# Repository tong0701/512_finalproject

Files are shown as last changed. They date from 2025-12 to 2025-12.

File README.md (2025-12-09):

# Bomb Master – 90s‑Style Handheld Reaction Game (ESP32‑C3 + CircuitPython)

## 1. Project Overview
Bomb Master is a 90s‑style handheld electronic reaction game. The OLED shows a command, you perform the matching physical action, the game checks timing/correctness, and you progress through 10 increasingly challenging levels.  
Hardware used: **ESP32‑C3 (Seeed XIAO), SSD1306 128×64 OLED, ADXL345 accelerometer, rotary encoder (with push button on D7 for game input), NeoPixel RGB LED, piezo buzzer, LiPo battery, independent hardware power switch.**

## 2. How to Play
### 2.1 Game Actions
- **LEFT** – rotate the encoder left  
- **RIGHT** – rotate the encoder right  
- **PRESS** – press the encoder/button (D7)  
- **SHAKE** – shake the device (detected by ADXL345)

### 2.2 Game Loop Structure
- Splash animation → "PRESS TO START"
- **Player name input** (3 characters, A-Z, using rotary encoder)
- Difficulty selection (Easy / Medium / Hard)
- Level start screen → press to ready → countdown (3,2,1,GO)
- Per‑move instruction (LEFT/RIGHT/PRESS; final move is SHAKE) with time limit and correctness check
- Level up after all moves; failure shows Game Over; after level 10 shows Win screen
- **High score board** (top 3 scores with player names) displayed after game ends

## 3. Difficulty Settings
- **Easy:** level time × 1.2  
- **Medium:** level time × 1.0  
- **Hard:** level time × 0.8  
SHAKE uses unified thresholds (magnitude > 13 or change > 3 or single change > 4, hold 1.5s); only time factor changes with difficulty.

## 4. Level Design (10 Levels)

| Level | Time Limit (base, s) | Moves | Notes |
|---|---|---|---|
| 1 | 25.0 | 3 | Last move = SHAKE |
| 2 | 22.0 | 4 | Last move = SHAKE |
| 3 | 19.0 | 5 | Last move = SHAKE |
| 4 | 17.0 | 6 | Last move = SHAKE |
| 5 | 14.0 | 7 | Last move = SHAKE |
| 6 | 12.0 | 8 | Last move = SHAKE |
| 7 | 10.0 | 9 | Last move = SHAKE |
| 8 | 8.5 | 10 | Last move = SHAKE |
| 9 | 7.0 | 11 | Last move = SHAKE |
| 10 | 6.0 | 12 | Last move = SHAKE |

Actual per‑difficulty time = base time × difficulty time factor above.

## 5. Hardware Components & Roles
- **ESP32‑C3 (XIAO):** runs CircuitPython game loop and state machine.  
- **SSD1306 OLED:** shows commands, timers, countdowns, and status.  
- **ADXL345 accelerometer:** detects SHAKE via magnitude/variation thresholds and hold time.  
- **Rotary encoder (CLK=D2, DT=D3, SW=D7):** primary input for LEFT/RIGHT rotations and PRESS action (D7 button for game input).  
- **NeoPixel (D0):** visual feedback (splash, success/fail, victory).  
- **Buzzer (D1, PWM):** audio cues for countdown, success, failure, splash.  
- **LiPo battery + independent hardware power switch:** portable power with physical on/off control (hardware switch, no GPIO, completely cuts battery connection).  

## 6. System & Circuit Diagrams
Documentation files are organized in the `Documentation/` folder:
- **Circuit diagrams** (`Documentation/circuit/`):
  - `circuit_diagrams.pdf` - Circuit schematic
  - `circuit_diagrams.kicad_sch` - KiCad source file
  - `circuit_diagrams.ps` - PostScript version
- **System diagrams** (`Documentation/system/`):
  - `systemdiagram.drawio.png` - System block diagram

## 7. Enclosure Design
- Handheld rectangular case; OLED window centered; encoder/button on front.  
- Cutouts for USB‑C and power switch; NeoPixel visible externally.  
- Internal battery compartment with access panel for service/debug.  
- 3D‑printed shell (e.g., PETG/PLA) for rigidity; non‑yellow filament per course constraint.

## 8. High Score System
- **Name Input**: Before difficulty selection, players enter a 3-character name (A-Z)
  - Use rotary encoder to select letters (rotate left/right)
  - Press button to confirm each character
  - After 3 characters are confirmed, press again to proceed
- **High Score Board**: Top 3 scores are saved to onboard memory (`highscores.txt`)
  - Scores are automatically sorted (highest first)
  - Displayed after game over or completion
  - Format: `1. ABC  1234`, `2. XYZ  1000`, `3. DEF  800`
  - New high scores trigger special animation
- **Persistent Storage**: High scores persist across power cycles (stored in microcontroller flash)

## 9. Running the Game
1. Flash **CircuitPython for ESP32‑C3** onto the XIAO.  
2. Copy required libs to `/lib/` on CIRCUITPY: `adafruit_ssd1306.mpy`, `adafruit_adxl34x.mpy`, `neopixel.mpy`, `adafruit_bus_device/` (and `adafruit_display_text/` if used).  
3. Copy `code.py` (from `src/` in this repo) to the root of CIRCUITPY as `code.py`.  
4. Eject and reset. Splash plays → enter name → choose difficulty → countdown → play.  

## 10. Repo Structure
```
bomb-master/
├── README.md                  # Project documentation
├── src/
│   └── code.py               # Main game code (CircuitPython)
├── docs/
│   └── CODE_STRUCTURE.md     # Code structure and flow guide
├── Documentation/
│   ├── circuit/              # Circuit diagrams
│   │   ├── circuit_diagrams.pdf
│   │   └── circuit_diagrams.kicad_sch
│   └── system/               # System diagrams
│       └── systemdiagram.drawio.png
└── lib/                       # Required CircuitPython libs (copy to device)
    ├── adafruit_ssd1306.mpy
    ├── adafruit_adxl34x.mpy
    ├── neopixel.mpy
    ├── adafruit_bus_device/
    └── adafruit_display_text/ (if used)
```

## 11. Future Improvements
- More move types or combo chains.  
- Richer 90s‑style sound/visual effects.  
- Dynamic difficulty scaling based on player performance.
- Additional statistics tracking (games played, average score, etc.).

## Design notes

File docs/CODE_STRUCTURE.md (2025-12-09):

# Bomb Master - Code Structure & Flow Guide

This document explains the complete code structure and execution flow of the Bomb Master game. Use this as a reference to understand how the game works and to prepare for questions.

---

## 📋 Table of Contents

1. [Overall Architecture](#overall-architecture)
2. [Hardware Setup](#hardware-setup)
3. [Core Components](#core-components)
4. [Game Flow](#game-flow)
5. [Key Functions Explained](#key-functions-explained)
6. [State Machine](#state-machine)
7. [Input Handling](#input-handling)
8. [Display & UI](#display--ui)
9. [Data Flow](#data-flow)

---

## 🏗️ Overall Architecture

The game follows a **single-file architecture** with clear sections:

```
code.py
├── Hardware Initialization (Lines 37-68)
├── Game Configuration (Lines 70-114)
├── Accelerometer Filter Class (Lines 116-187)
├── Encoder Class (Lines 189-252)
├── Helper Functions (Lines 261-323)
├── High Score Management (Lines 325-368)
├── Name Input (Lines 370-435)
├── High Score Board Display (Lines 437-465)
├── Difficulty Selection Menu (Lines 467-509)
├── UI Functions (Lines 511-706)
├── Animation Functions (Lines 642-798)
├── Game Logic Functions (Lines 800-999)
└── Main Game Loop (Lines 1001-1093)
```

**Design Pattern**: Event-driven with state machine (menu → game → results)

---

## 🔌 Hardware Setup

### Pin Mapping
- **OLED (I2C)**: SCL=D5, SDA=D4
- **Accelerometer (I2C)**: Shared bus with OLED
- **Rotary Encoder**: CLK=D2, DT=D3, SW=D7 (button)
- **NeoPixel**: D0
- **Buzzer (PWM)**: D1

### Hardware Initialization Order
1. Initialize I2C bus
2. Initialize OLED display
3. Initialize accelerometer (optional, with error handling)
4. Initialize NeoPixel (optional)
5. Initialize buzzer/PWM (optional)

**Note**: All hardware has try-except blocks to prevent crashes if hardware is missing.

---

## 🧩 Core Components

### 1. AccelerometerFilter Class
**Purpose**: Smooth accelerometer readings and auto-calibration

**How it works**:
- Uses 5-sample moving average filter
- Auto-calibrates on initialization (10 samples, calculates offset)
- Removes gravity offset (assumes Z-axis has ~9.8 m/s² gravity)
- Provides `get_magnitude()` for shake detection

**Key Methods**:
- `calibrate()`: Measures static position, calculates offset
- `read()`: Returns filtered (x, y, z) values
- `get_magnitude()`: Returns total acceleration magnitude

### 2. DebouncedEncoder Class
**Purpose**: Read rotary encoder input reliably

**How it works**:
- Detects CLK falling edge (simplified, fast response)
- Debounce time: 0.001s (very fast)
- Returns 'left' or 'right' direction
- `get_menu_navigation()`: Converts encoder direction to menu navigation (up/down)

**Key Methods**:
- `get_direction()`: Returns 'left' or 'right' or None
- `get_menu_navigation()`: Returns 'up' or 'down' or None
- `reset()`: Resets encoder state

### 3. Game Configuration
**Constants**:
- `TARGET_SCORE = 60`: Score needed to complete rotation actions
- `KNOB_MULTIPLIER = 30`: Points per encoder click
- `REACTION_TIME = 1.0`: Delay before showing new action

**DIFFICULTIES Dictionary**:
- `time_factor`: Multiplies level time (EASY: 1.2x, MEDIUM: 1.0x, HARD: 0.8x)
- `shake_threshold`: Unified magnitude threshold (13)
- `shake_change_threshold`: Accumulated change threshold (3)

**LEVELS List**:
- 10 levels, each with `time` and `moves`
- Time decreases, moves increase with level number

---

## 🎮 Game Flow

### Main Loop Structure

```
Power On
  ↓
Splash Animation (draw_upgraded_splash)
  ↓
"Press to Start" Screen (wait_for_press)
  ↓
Player Name Input (input_player_name)
  - 3 characters (A-Z)
  - Rotary encoder to select
  - Press to confirm each character
  ↓
Difficulty Selection Menu (show_difficulty_menu)
  ↓
┌─────────────────────────────────┐
│ Main Game Loop                  │
│                                 │
│  For each level (0-9):         │
│    ├─ Level Start Screen       │
│    ├─ Countdown (3-2-1-GO)     │
│    ├─ Run Level                │
│    │   ├─ For each move:       │
│    │   │   ├─ Choose action    │
│    │   │   ├─ Wait reaction    │
│    │   │   ├─ Action loop      │
│    │   │   └─ Check success    │
│    │   └─ Level complete       │
│    │                            │
│    ├─ Success?                  │
│    │   ├─ Yes → Next Level     │
│    │   └─ No → Game Over       │
│                                 │
│  All Levels Complete            │
│    └─ Win Screen                │
│                                 │
└─────────────────────────────────┘
  ↓
High Score Check
  - Check if score qualifies for top 3
  - If yes: Add to high score board with player name
  - Show "NEW HIGH SCORE!" animation (if qualified)
  ↓
High Score Board Display (show_high_score_board)
  - Show top 3 scores with player names
  - Press to continue
  ↓
Return to Splash (loop restarts)
```

### Detailed Level Execution Flow

```
run_level() is called
  ↓
Show "LEVEL X" screen → wait_for_press()
  ↓
run_countdown() → 3, 2, 1, GO!
  ↓
Initialize:
  - level_start_time = current time
  - score = 0
  - encoder.reset()
  ↓
┌──────────────────────────────────────┐
│ For each move in level:             │
│                                      │
│  1. Choose action:                  │
│     - Last move = SHAKE             │
│     - Others = random(LEFT/RIGHT/   │
│       PRESS)                         │
│                                      │
│  2. Reaction time delay (1.0s)      │
│     - Check if level time expired   │
│                                      │
│  3. Action execution loop:          │
│     ┌─────────────────────────────┐ │
│     │ while True:                 │ │
│     │   - Check level time        │ │
│     │   - Read encoder            │ │
│     │   - Read accelerometer      │ │
│     │   - Check button            │ │
│     │   - Update display          │ │
│     │   - Check action success    │ │
│     │   - Break if done/timeout   │ │
│     └─────────────────────────────┘ │
│                                      │
│  4. Success?                        │
│     - Yes: score += 10, continue    │
│     - No: return False, score       │
│                                      │
└──────────────────────────────────────┘
  ↓
All moves complete
  ↓
score += 50 (level bonus)
  ↓
draw_success_animation()
  ↓
Return True, score
```

---

## 🔑 Key Functions Explained

### Hardware Functions

#### `safe_show()`
**Purpose**: Safely update OLED display
- Wraps `display.show()` in try-except
- Prevents crashes from I2C errors

#### `tone(freq, duration)`
**Purpose**: Play buzzer sound
- Sets PWM frequency and duty cycle
- Plays for duration, then stops

### UI Functions

#### `draw_centered_text(text, y, color=1)`
**Purpose**: Draw text centered on screen
- Calculates x position: `(128 - text_width) // 2`
- Text width = `len(text) * 6` (6 pixels per char)

#### `draw_game_ui(target, progress_pct, level_time_pct, score, level)`
**Purpose**: Draw complete in-game UI
- Top: Level number (L1-L10) and Score
- Top progress bar: Level time remaining
- Center: Action instruction (LEFT/RIGHT/PRESS/SHAKE)
- Bottom progress bar: Action completion progress
- Updates every 0.05s (controlled in game loop)

#### `show_message_box(title, line1, line2, invert)`
**Purpose**: Display centered message with border
- Used for level start, game over, win screens

### Animation Functions

#### `draw_upgraded_splash()`
**Purpose**: Boot animation
- Phase 1: Bomb grows (8 frames)
- Phase 2: Explosion particles (15 frames)
- Phase 3: Title pops up (12 frames)
- Phase 4: Title flashes twice
- Only plays once per boot (`splash_played` flag)

#### `draw_success_animation()`
**Purpose**: Fireworks animation on level complete
- Creates 36 particles in circle
- Particles spread with gravity
- NeoPixel rainbow effect
- Plays for ~1.5 seconds total

#### `draw_fail_animation()`
**Purpose**: Flash animation on failure
- Inverts screen 5 times
- Red NeoPixel flash
- Descending buzzer tone

### Game Logic Functions

#### `input_player_name()`
**Purpose**: Input 3-character player name before difficulty selection
- Uses rotary encoder to select A-Z
- Press button to confirm each character
- Returns string of 3 characters
- Display shows current selection with cursor underline

#### `show_high_score_board()`
**Purpose**: Display top 3 high scores with player names
- Reads from `highscores.txt`
- Shows: `1. ABC  1234`, `2. XYZ  1000`, etc.
- Waits for button press to continue

#### `is_high_score(score)`
**Purpose**: Check if score qualifies for top 3
- Returns True if board has < 3 entries OR score > 3rd place score

#### `add_high_score(name, score)`
**Purpose**: Add new high score and maintain top 3
- Adds entry, sorts by score (descending), keeps only top 3
- Saves to `highscores.txt`
- Returns updated list

#### `show_difficulty_menu()`
**Purpose**: Difficulty selection screen
- Displays EASY, MEDIUM, HARD with cursor
- Uses encoder to navigate (up/down)
- Button press selects difficulty
- Returns selected difficulty string

#### `run_countdown()`
**Purpose**: 3-2-1-GO countdown
- Shows centered numbers
- Yellow NeoPixel, beep sound
- "GO!" with green NeoPixel, long beep

#### `run_level(level_idx, config, difficulty)`
**Purpose**: Execute a single level
- Parameters:
  - `level_idx`: Level number (0-9)
  - `config`: Level config dict (time, moves)
  - `difficulty`: Difficulty string
- Returns: `(success: bool, score: int)`

**Level Execution Details**:
1. Show level start screen → wait for press
2. Countdown
3. For each move:
   - Choose action (random or SHAKE for last)
   - Wait reaction time
   - Action loop:
     - Check level time limit
     - Detect input (encoder/button/shake)
     - Update progress bar
     - Check if action complete
   - If action failed → return False
4. All moves complete → return True with score

---

## 🎯 State Machine

The game uses an implicit state machine:

```
State: SPLASH
  - Play splash animation
  - Wait for button
  → Transition to MENU

State: MENU
  - Show difficulty selection
  - Navigate with encoder
  - Select with button
  → Transition to GAME

State: GAME
  - For each level:
    - Show level start → wait
    - Countdown
    - Execute moves
    - Check success/failure
  → Transition to RESULT (WIN/GAME_OVER)

State: RESULT
  - Show score/high score
  - Check for new high score
  - Wait for button
  → Transition to SPLASH (loop)
```

---

## 🎮 Input Handling

### Encoder Input (LEFT/RIGHT Actions)
**Detection**:
- `encoder.get_direction()` returns 'left' or 'right'
- Checked every loop iteration (0.01s delay)
- For LEFT action: accumulate score when direction == 'left'
- For RIGHT action: accumulate score when direction == 'right'
- Score increases by `KNOB_MULTIPLIER` (30) per click
- When `accumulated_score >= TARGET_SCORE` (60), action complete

### Button Input (PRESS Action)
**Detection**:
- `button.value == False` means pressed (pull-up resistor)
- Checked every loop iteration
- When PRESS action active and button pressed → action complete

### Accelerometer Input (SHAKE Action)
**Detection** (Multi-threshold approach):
1. **Magnitude trigger**: `current_magnitude > 13`
2. **Change trigger**: `accumulated_change > 3` (within 0.2s window)
3. **Big change trigger**: `magnitude_change > 4` (single large change)

**Hold mechanism**:
- Once triggered, must hold for `shake_hold_duration` (1.5s)
- Progress bar shows hold progress
- If trigger conditions met, action completes after hold time

### Menu Navigation
**Detection**:
- `encoder.get_menu_navigation()` converts encoder direction to menu direction
- Right rotation = Down (next option)
- Left rotation = Up (previous option)
- Menu polls at high frequency (0.001s delay) for responsiveness

---

## 📺 Display & UI

### Screen Layout (128x64 pixels)

**In-Game UI** (`draw_game_ui`):
```
┌────────────────────────────────────┐
│ L1              S:100              │  ← Top bar (Level & Score)
│ ━━━━━━━━━━━━━━━━━━━━━━━━━━━━━━━━━ │  ← Level time progress bar
│                                    │
│           CUT BLUE                 │  ← Action theme
│           << LEFT                  │  ← Action instruction
│                                    │
│                                    │
│        ━━━━━━━━━━━━━━━━━━         │  ← Action progress bar
└────────────────────────────────────┘
```

**Menu UI** (`show_difficulty_menu`):
```
┌────────────────────────────────────┐
│                                    │
│           > EASY                   │  ← y=8
│             MEDIUM                 │  ← y=21
│             HARD                   │  ← y=34
│                                    │
│         Rotate/Press               │  ← y=48
└────────────────────────────────────┘
```

**Message Box** (`show_message_box`):
```
┌────────────────────────────────────┐
│ ╔═══════════════════════════════╗ │
│ ║          TITLE                ║ │  ← Title (y=15)
│ ║                               ║ │
│ ║          Line 1               ║ │  ← Line 1 (y=30)
│ ║          Line 2               ║ │  ← Line 2 (y=42)
│ ╚═══════════════════════════════╝ │
└────────────────────────────────────┘
```

### Display Update Strategy
- **Game UI**: Updated every 0.05s (20 FPS) in game loop
- **Menu**: Updated every loop iteration (high frequency)
- **Animations**: Frame-based (0.04-0.05s per frame)

---

## 📊 Data Flow

### Score Flow
```
Each successful action: +10 points
Level complete bonus: +50 points
Total score = sum of all level scores
```

### High Score Flow
```
Game ends
  ↓
Check: is_high_score(total_score)?
  - Compares with 3rd place or checks if board has < 3 entries
  ↓
Yes → Add player_name and score to high score board
      → Sort and keep top 3
      → Save to highscores.txt (format: "NAME,SCORE")
      → Show "NEW HIGH SCORE!" animation
  ↓
Show high score board (top 3 with names)
  ↓
Press to continue
```

### Name Input Flow
```
After splash screen
  ↓
Display "ENTER NAME"
  ↓
For each of 3 characters:
  - Rotate encoder: Select A-Z
  - Press: Confirm character → Move to next
  ↓
After 3rd character confirmed:
  - Press again → Proceed to difficulty selection
```

### Time Management
```
Level start:
  level_start_time = current_time
  level_time_limit = base_time * difficulty_factor

Each loop:
  elapsed = current_time - level_start_time
  level_time_pct = elapsed / level_time_limit
  
  if elapsed >= level_time_limit:
    → Game Over
```

### Action Progress Tracking

**Rotation Actions (LEFT/RIGHT)**:
```
accumulated_score = 0
Each encoder click in correct direction:
  accumulated_score += KNOB_MULTIPLIER (30)
  
progress_pct = accumulated_score / TARGET_SCORE (60)
  
When progress_pct >= 1.0:
  → Action complete
```

**SHAKE Action**:
```
shake_triggered = False
shake_trigger_time = 0

When shake detected:
  shake_triggered = True
  shake_trigger_time = current_time

progress_pct = (current_time - shake_trigger_time) / 1.5

When progress_pct >= 1.0:
  → Action complete
```

---

## 🔄 Common Patterns

### Error Handling Pattern
```python
try:
    # Hardware operation
    display.show()
except:
    pass  # Fail silently, prevent crash
```

### Hardware Check Pattern
```python
if pixels:
    try:
        pixels.fill((255, 0, 0))
    except:
        pass
```

### Non-blocking Loop Pattern
```python
while True:
    # Do work
    # Check conditions
    time.sleep(0.01)  # Prevent freeze
```

### Progress Bar Drawing Pattern
```python
# Draw border
display.rect(x, y, width, height, 1)

# Calculate fill
fill_w = int(progress_pct * (width - 2))
fill_w = min(max(fill_w, 0), width - 2)  # Clamp

# Draw fill
if fill_w > 0:
    display.fill_rect(x + 1, y + 1, fill_w, height - 2, 1)
```

---

## 📝 Key Constants Reference

| Constant | Value | Purpose |
|---|---|---|
| `TARGET_SCORE` | 60 | Score needed to complete rotation actions |
| `KNOB_MULTIPLIER` | 30 | Points per encoder click |
| `REACTION_TIME` | 1.0s | Delay before showing new action |
| `shake_hold_duration` | 1.5s | Time to hold shake action |
| `debounce_time` | 0.001s | Encoder debounce time |
| `display_update_interval` | 0.05s | UI update frequency |

---

## 🎓 Understanding the Code for Questions

### How to explain the game flow:
1. **Start**: Splash animation → difficulty selection → game begins
2. **Level structure**: 10 levels, increasing difficulty
3. **Move execution**: Random actions (LEFT/RIGHT/PRESS), last is always SHAKE
4. **Scoring**: +10 per move, +50 per level
5. **Time management**: Each level has time limit, difficulty affects time
6. **End conditions**: Time runs out → Game Over, all levels complete → Win

### How to explain input detection:
1. **Encoder**: Detects CLK falling edge, checks DT pin for direction
2. **Button**: Pull-up resistor, False = pressed
3. **Shake**: Multi-threshold (magnitude + change + big change), must hold 1.5s

### How to explain filtering:
1. **Accelerometer**: 5-sample moving average, auto-calibrates on boot
2. **Encoder**: Debounce (0.001s) to prevent noise

### How to explain difficulty:
- Only affects **time factor** (EASY: 1.2x, MEDIUM: 1.0x, HARD: 0.8x)
- Shake thresholds are **unified** across all difficulties
- More time = easier to complete moves

---

## 🚀 Quick Reference for Common Questions

**Q: How does the encoder work?**
- A: Detects CLK falling edge, checks DT pin state to determine direction. Uses debouncing (0.001s) for reliability.

**Q: How is shake detected?**
- A: Three triggers: total magnitude > 13, accumulated change > 3, or single change > 4. Must hold for 1.5 seconds after trigger.

**Q: How does scoring work?**
- A: +10 points per successful action, +50 bonus per completed level. Top 3 high scores saved with player names to `highscores.txt`.

**Q: What happens when time runs out?**
- A: Game immediately ends, shows Game Over screen, checks for high score.

**Q: How are actions chosen?**
- A: Random selection from LEFT/RIGHT/PRESS for first N-1 moves. Last move is always SHAKE.

**Q: How does difficulty affect gameplay?**
- A: Only affects time limit (multiplier: 1.2x/1.0x/0.8x). All other mechanics stay the same.

**Q: How does the high score board work?**
- A: Before difficulty selection, players enter 3-character name (A-Z) using encoder. Top 3 scores are saved with names to onboard memory. High score board displays after game ends.

---

**End of Guide**

Use this document to understand the code structure and prepare for technical questions about the game implementation.

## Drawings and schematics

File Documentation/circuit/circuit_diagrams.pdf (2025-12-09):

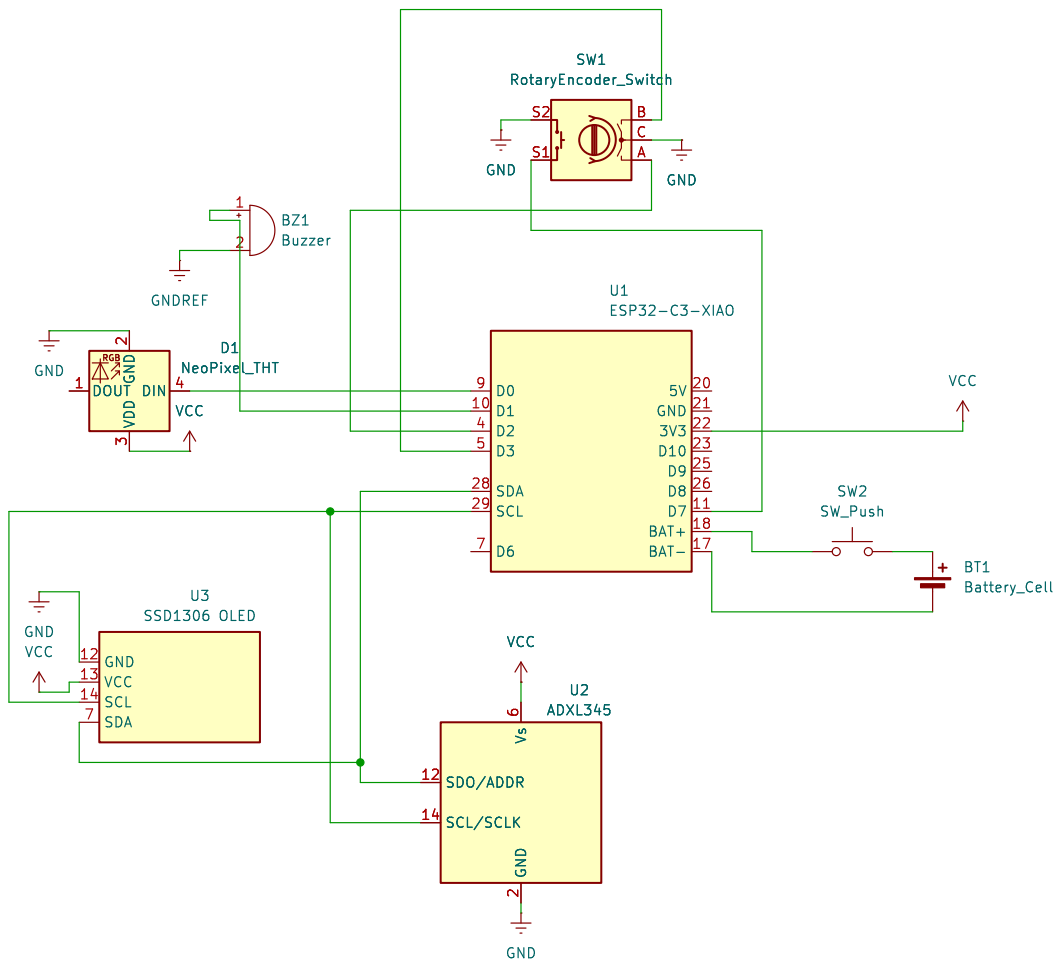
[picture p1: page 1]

Id: 1/1 Title: File: circuit_diagrams.kicad_sch Sheet: /

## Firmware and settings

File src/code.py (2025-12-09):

"""
Bomb Master - Bop-It Style Reaction Game for ESP32-C3 (CircuitPython)

Hardware Pin Map:
- OLED SSD1306 (I2C): SCL=D5, SDA=D4
- ADXL345 Accelerometer (I2C): Shared bus
- Rotary Encoder: CLK=D2, DT=D3, SW=D7 (PRESS button for game input)
- NeoPixel RGB LED: D0
- Buzzer PWM: D1
- LiPo Battery + Independent Power Switch (hardware switch, controls battery connection, no GPIO)

Required Libraries (place in /lib folder):
- adafruit_ssd1306
- adafruit_framebuf (usually bundled)
- adafruit_adxl34x
- neopixel (usually built-in)

Game Features:
- Difficulty selection (EASY, MEDIUM, HARD)
- 10 levels with progressive difficulty
- 4 action types (LEFT, RIGHT, PRESS, SHAKE)
- Score system with high score persistence
- Filtered accelerometer with calibration
- Improved encoder detection
- Polished animations and UI
"""

import time
import board
import busio
import digitalio
import neopixel
import random
import adafruit_ssd1306
import adafruit_adxl34x

# ==================== HARDWARE INITIALIZATION ====================

# I2C Bus
try:
    i2c = busio.I2C(board.D5, board.D4, frequency=1000000)
except:
    i2c = busio.I2C(board.D5, board.D4)

# OLED Display
display = adafruit_ssd1306.SSD1306_I2C(128, 64, i2c)

# Accelerometer
accel = None
try:
    accel = adafruit_adxl34x.ADXL345(i2c)
except:
    pass

# NeoPixel RGB LED (D0)
pixels = None
try:
    pixels = neopixel.NeoPixel(board.D0, 1, brightness=0.3)
except:
    pass

# Buzzer
buzzer = None
try:
    import pwmio
    buzzer = pwmio.PWMOut(board.D1, variable_frequency=True)
except:
    pass

# ==================== GAME CONFIGURATION ====================

# Base game settings
TARGET_SCORE = 60
KNOB_MULTIPLIER = 30
REACTION_TIME = 1.0

# Difficulty settings (ordered: EASY, MEDIUM, HARD)
DIFFICULTIES = {
    "EASY": {
        "time_factor": 1.2,
        "shake_threshold": 13,  # Unified threshold: total magnitude (range ~10-16 based on user data)
        "shake_change_threshold": 3,  # Unified threshold: accumulated change (adjacent change ~1-5)
        "name": "EASY"
    },
    "MEDIUM": {
        "time_factor": 1.0,
        "shake_threshold": 13,  # Unified threshold, same for all difficulties
        "shake_change_threshold": 3,  # Unified threshold
        "name": "MEDIUM"
    },
    "HARD": {
        "time_factor": 0.8,
        "shake_threshold": 13,  # Unified threshold, same for all difficulties
        "shake_change_threshold": 3,  # Unified threshold
        "name": "HARD"
    }
}

# Ensure order: EASY, MEDIUM, HARD
DIFFICULTY_ORDER = ["EASY", "MEDIUM", "HARD"]

# Level definitions (base time and moves)
LEVELS = [
    {"time": 25.0, "moves": 3},
    {"time": 22.0, "moves": 4},
    {"time": 19.0, "moves": 5},
    {"time": 17.0, "moves": 6},
    {"time": 14.0, "moves": 7},
    {"time": 12.0, "moves": 8},
    {"time": 10.0, "moves": 9},
    {"time": 8.5, "moves": 10},
    {"time": 7.0, "moves": 11},
    {"time": 6.0, "moves": 12},
]

# ==================== ACCELEROMETER FILTERING ====================

class AccelerometerFilter:
    """5-sample moving average filter for accelerometer"""
    def __init__(self, accel_sensor):
        self.accel = accel_sensor
        self.samples = [[0, 0, 0] for _ in range(5)]
        self.index = 0
        self.calibrated = False
        self.offset = [0, 0, 0]
        
        # Auto-calibration on init
        if self.accel:
            self.calibrate()
    
    def calibrate(self):
        """Auto-calibrate accelerometer (zero offset)"""
        if not self.accel:
            return
        
        samples = []
        for _ in range(10):
            try:
                x, y, z = self.accel.acceleration
                samples.append([x, y, z])
            except:
                pass
            time.sleep(0.05)
        
        if samples:
            # Calculate average (expected gravity on Z axis ~9.8)
            avg_x = sum(s[0] for s in samples) / len(samples)
            avg_y = sum(s[1] for s in samples) / len(samples)
            avg_z = sum(s[2] for s in samples) / len(samples)
            
            # Set offset (assuming device is stationary)
            self.offset = [avg_x, avg_y, avg_z - 9.8]
            self.calibrated = True
    
    def read(self):
        """Read filtered acceleration values"""
        if not self.accel:
            return (0, 0, 9.8)
        
        try:
            x, y, z = self.accel.acceleration
            # Apply offset calibration
            if self.calibrated:
                x -= self.offset[0]
                y -= self.offset[1]
                z -= self.offset[2]
            
            # Add to circular buffer
            self.samples[self.index] = [x, y, z]
            self.index = (self.index + 1) % 5
            
            # Calculate moving average
            avg_x = sum(s[0] for s in self.samples) / 5
            avg_y = sum(s[1] for s in self.samples) / 5
            avg_z = sum(s[2] for s in self.samples) / 5
            
            return (avg_x, avg_y, avg_z)
        except:
            return (0, 0, 9.8)
    
    def get_magnitude(self):
        """Get total acceleration magnitude"""
        x, y, z = self.read()
        return (x**2 + y**2 + z**2)**0.5

# Initialize filtered accelerometer
accel_filter = AccelerometerFilter(accel)

# ==================== ENCODER WITH DEBOUNCING ====================

class DebouncedEncoder:
    """Simplified encoder - direct response, removed delay restrictions"""
    def __init__(self, pin_clk, pin_dt):
        self.clk = digitalio.DigitalInOut(pin_clk)
        self.clk.direction = digitalio.Direction.INPUT
        self.clk.pull = digitalio.Pull.UP
        
        self.dt = digitalio.DigitalInOut(pin_dt)
        self.dt.direction = digitalio.Direction.INPUT
        self.dt.pull = digitalio.Pull.UP
        
        self.last_clk = self.clk.value
        self.last_dt = self.dt.value
        self.last_edge_time = time.monotonic()
        self.debounce_time = 0.001  # Reduced debounce time for faster response
    
    def get_direction(self):
        """Get encoder direction - simplified version, immediate response"""
        clk = self.clk.value
        dt = self.dt.value
        now = time.monotonic()
        
        direction = None
        
        # Only detect CLK falling edge (simplified, faster response)
        if self.last_clk and not clk:
            if now - self.last_edge_time >= self.debounce_time:
                self.last_edge_time = now
                if dt:
                    direction = 'right'
                else:
                    direction = 'left'
                # Update state immediately
                self.last_clk = clk
                self.last_dt = dt
                return direction
        
        self.last_clk = clk
        self.last_dt = dt
        return None
    
    def get_menu_navigation(self):
        """
        Get menu navigation direction - directly uses get_direction
        Right = Down (next)
        Left = Up/Previous
        """
        direction = self.get_direction()
        
        if direction == 'right':
            return 'down'
        elif direction == 'left':
            return 'up'
        
        return None
    
    def reset(self):
        """Reset encoder state"""
        self.last_clk = self.clk.value
        self.last_dt = self.dt.value
        self.last_edge_time = time.monotonic()

# Initialize encoder
encoder = DebouncedEncoder(board.D2, board.D3)

# Button (encoder switch)
button = digitalio.DigitalInOut(board.D7)
button.direction = digitalio.Direction.INPUT
button.pull = digitalio.Pull.UP

# ==================== HELPER FUNCTIONS ====================

def safe_show():
    """Safely update display"""
    try:
        display.show()
    except:
        pass

def tone(freq, duration):
    """Play buzzer tone"""
    if buzzer:
        try:
            buzzer.frequency = int(freq)
            buzzer.duty_cycle = 32768
            time.sleep(duration)
            buzzer.duty_cycle = 0
        except:
            pass
    else:
        time.sleep(duration)

def draw_centered_text(text, y, color=1):
    """Draw centered text"""
    x = max(0, (128 - len(text) * 6) // 2)
    display.text(text, x, y, color)

def draw_bold_text(text, x, y, color=1):
    """Draw bold text by drawing twice with 1px offset"""
    display.text(text, x, y, color)
    display.text(text, x + 1, y, color)
    # Optional: draw with vertical offset for enhanced bold effect
    # display.text(text, x, y + 1, color)

def draw_large_text(text, x, y, color=1, scale=2):
    """Draw larger text by scaling (simple pixel doubling)"""
    # Simple scaling: each character drawn as 2x2 pixel block
    # Note: This is simplified version, better effect requires custom font
    for i, char in enumerate(text):
        char_x = x + i * 6 * scale
        # Draw character multiple times (offset) to simulate scaling
        display.text(char, char_x, y, color)
        if scale >= 2:
            display.text(char, char_x + 1, y, color)
            display.text(char, char_x, y + 1, color)
            display.text(char, char_x + 1, y + 1, color)

def draw_centered_bold_text(text, y, color=1):
    """Draw centered bold text"""
    x = max(0, (128 - len(text) * 6) // 2)
    draw_bold_text(text, x, y, color)

def wait_for_press():
    """Wait for button press"""
    while True:
        encoder.get_direction()  # Keep encoder active
        if button.value == False:
            tone(1500, 0.1)
            while button.value == False:
                time.sleep(0.01)
            time.sleep(0.1)
            return
        time.sleep(0.01)

# ==================== HIGH SCORE MANAGEMENT ====================

HIGH_SCORES_FILE = "highscores.txt"

def load_high_scores():
    """Load top 3 high scores from file"""
    try:
        with open(HIGH_SCORES_FILE, 'r') as f:
            lines = f.readlines()
            scores = []
            for line in lines[:3]:  # Only top 3
                parts = line.strip().split(',')
                if len(parts) == 2:
                    name = parts[0].strip()
                    score = int(parts[1].strip())
                    scores.append({'name': name, 'score': score})
            return scores
    except:
        return []

def save_high_scores(scores):
    """Save top 3 high scores to file"""
    try:
        with open(HIGH_SCORES_FILE, 'w') as f:
            for entry in scores[:3]:  # Only save top 3
                f.write(f"{entry['name']},{entry['score']}\n")
    except:
        pass

def add_high_score(name, score):
    """Add a new high score and return updated list (top 3)"""
    scores = load_high_scores()
    scores.append({'name': name, 'score': score})
    scores.sort(key=lambda x: x['score'], reverse=True)  # Sort by score descending
    scores = scores[:3]  # Keep only top 3
    save_high_scores(scores)
    return scores

def is_high_score(score):
    """Check if score qualifies for high score board (top 3)"""
    scores = load_high_scores()
    if len(scores) < 3:
        return True
    return score > scores[-1]['score']  # Compare with 3rd place

# ==================== NAME INPUT ====================

def input_player_name():
    """Input player name (3 characters) using encoder"""
    name = ['A', 'A', 'A']  # Initial letters
    current_pos = 0  # Current character position (0, 1, 2)
    current_char_idx = 0  # Current character index in alphabet (0-25 for A-Z)
    
    alphabet = 'ABCDEFGHIJKLMNOPQRSTUVWXYZ'
    
    while True:
        display.fill(0)
        display.rect(0, 0, 128, 64, 1)
        
        # Title
        draw_centered_text("ENTER NAME", 8, 1)
        
        # Display name with cursor
        name_str = ''.join(name)
        x_start = (128 - len(name_str) * 6) // 2
        y_pos = 28
        
        for i, char in enumerate(name_str):
            x_pos = x_start + i * 6
            if i == current_pos:
                # Draw cursor (underline or highlight)
                display.fill_rect(x_pos - 1, y_pos + 8, 8, 2, 1)
                display.text(char, x_pos, y_pos, 0)  # Inverted
            else:
                display.text(char, x_pos, y_pos, 1)
        
        # Instructions
        draw_centered_text("Rotate: Change", 45, 1)
        draw_centered_text("Press: Confirm", 54, 1)
        
        safe_show()
        
        # Handle encoder navigation
        direction = encoder.get_direction()
        if direction == 'right':
            current_char_idx = (current_char_idx + 1) % 26
            name[current_pos] = alphabet[current_char_idx]
            tone(600, 0.02)
            time.sleep(0.05)
        elif direction == 'left':
            current_char_idx = (current_char_idx - 1) % 26
            name[current_pos] = alphabet[current_char_idx]
            tone(600, 0.02)
            time.sleep(0.05)
        
        # Handle button press
        if button.value == False:
            tone(1500, 0.1)
            while button.value == False:
                time.sleep(0.01)
            time.sleep(0.1)
            
            # Move to next character
            current_pos += 1
            if current_pos >= 3:
                # All characters selected, return name
                return ''.join(name)
            # Reset character index for next position
            current_char_idx = alphabet.index(name[current_pos])
        
        time.sleep(0.01)

# ==================== HIGH SCORE BOARD DISPLAY ====================

def show_high_score_board():
    """Display top 3 high scores"""
    scores = load_high_scores()
    
    while True:
        display.fill(0)
        display.rect(0, 0, 128, 64, 1)
        
        # Title
        draw_centered_text("HIGH SCORES", 5, 1)
        
        # Display top 3 scores
        y_start = 18
        for i, entry in enumerate(scores[:3]):
            rank = f"{i+1}."
            name = entry['name']
            score = entry['score']
            line = f"{rank} {name}  {score}"
            
            # Left align with some offset
            x_pos = 8
            y_pos = y_start + i * 14
            display.text(line, x_pos, y_pos, 1)
        
        # Instructions
        if len(scores) == 0:
            draw_centered_text("No scores yet", 35, 1)
        
        draw_centered_text("Press to continue", 54, 1)
        
        safe_show()
        
        # Wait for button press
        if button.value == False:
            tone(1500, 0.1)
            while button.value == False:
                time.sleep(0.01)
            time.sleep(0.1)
            return
        
        time.sleep(0.01)

# ==================== DIFFICULTY SELECTION MENU ====================

def show_difficulty_menu():
    """Show difficulty selection menu, return selected difficulty"""
    difficulty_names = DIFFICULTY_ORDER  # Ensure order: EASY, MEDIUM, HARD
    selected_idx = 0  # Default selection: EASY
    
    while True:
        display.fill(0)
        display.rect(0, 0, 128, 64, 1)
        
        # Menu items (centered, y positions: 8, 21, 34)
        for i, diff_name in enumerate(difficulty_names):
            y_pos = 8 + i * 13  # y=8, 21, 34
            prefix = "> " if i == selected_idx else "  "
            text = prefix + diff_name
            x_pos = (128 - len(text) * 6) // 2
            display.text(text, x_pos, y_pos, 1)
        
        # Instructions (bottom, y=48)
        draw_centered_text("Rotate/Press", 48, 1)
        
        safe_show()
        
        # High-speed polling for immediate response
        nav = encoder.get_menu_navigation()
        if nav == 'down':
            selected_idx = (selected_idx + 1) % len(difficulty_names)
            tone(800, 0.02)
            time.sleep(0.02)  # Very short delay
        elif nav == 'up':
            selected_idx = (selected_idx - 1) % len(difficulty_names)
            tone(800, 0.02)
            time.sleep(0.02)  # Very short delay
        
        # Check button
        if button.value == False:
            tone(1500, 0.1)
            while button.value == False:
                time.sleep(0.01)
            time.sleep(0.1)
            return difficulty_names[selected_idx]
        
        time.sleep(0.001)  # Very short delay, maximum frequency polling

# ==================== BOMB EXPLOSION SPLASH ANIMATION ====================

splash_played = False

def draw_upgraded_splash():
    """Bomb explosion animation - explosion effect then BOMB MASTER title pops up"""
    global splash_played
    if splash_played:
        return
    splash_played = True
    
    # Phase 1: Bomb appears (center dot)
    center_x, center_y = 64, 32
    for frame in range(8):
        display.fill(0)
        # Bomb (small dot, gradually grows)
        size = frame * 2
        if size > 0:
            display.fill_rect(center_x - size//2, center_y - size//2, size, size, 1)
        safe_show()
        if pixels:
            try:
                # Red flicker
                pixels.fill((min(255, frame * 30), 0, 0))
            except:
                pass
        time.sleep(0.05)
    
    # Phase 2: Explosion effect (outward spreading particles)
    particles = []
    for angle in range(0, 360, 15):  # 24 particles in different directions
        rad = angle * 3.14159 / 180
        particles.append({
            'x': center_x,
            'y': center_y,
            'vx': __import__('math').cos(rad) * 2,
            'vy': __import__('math').sin(rad) * 2,
            'life': 15
        })
    
    for frame in range(15):
        display.fill(0)
        
        # Draw explosion particles
        for p in particles:
            if p['life'] > 0:
                p['x'] += p['vx']
                p['y'] += p['vy']
                p['life'] -= 1
                
                x, y = int(p['x']), int(p['y'])
                if 0 <= x < 128 and 0 <= y < 64:
                    display.fill_rect(x, y, 2, 2, 1)
        
        # Center explosion light
        if frame < 10:
            for i in range(3):
                size = (frame + i) * 3
                display.rect(center_x - size//2, center_y - size//2, size, size, 1)
        
        safe_show()
        
        # NeoPixel red explosion effect
        if pixels:
            try:
                intensity = max(0, 255 - frame * 15)
                pixels.fill((intensity, intensity // 3, 0))
            except:
                pass
        
        if frame == 5:
            tone(200, 0.1)  # Low-pitched explosion sound
        
        time.sleep(0.04)
    
    # Phase 3: Title pops up (scales from center)
    title_frames = 12
    for frame in range(title_frames):
        display.fill(0)
        
        # Title scales from center
        scale = frame / title_frames
        if scale > 0.3:  # Start displaying at 30%
            # Simple scaling effect (simulated with different text sizes)
            if scale < 0.6:
                # Small title
                draw_centered_text("BOMB", 28, 1)
                draw_centered_text("MASTER", 38, 1)
            else:
                # Normal size
                draw_centered_text("BOMB MASTER", 25, 1)
        
        # Remaining explosion particles (fade out)
        for p in particles:
            if p['life'] > 0:
                x, y = int(p['x']), int(p['y'])
                if 0 <= x < 128 and 0 <= y < 64:
                    display.fill_rect(x, y, 1, 1, 1)
        
        safe_show()
        
        # NeoPixel fades to yellow/orange
        if pixels:
            try:
                if frame < title_frames // 2:
                    pixels.fill((255 - frame * 20, 100 + frame * 10, 0))
                else:
                    pixels.fill((155, 200, 0))
            except:
                pass
        
        if frame == 3:
            tone(800, 0.1)  # Title appearance sound
        if frame == 8:
            tone(1200, 0.1)
        
        time.sleep(0.05)
    
    # Final state: Title flashes twice
    for flash in range(2):
        display.fill(0)
        draw_centered_text("BOMB MASTER", 25, 1)
        display.rect(0, 0, 128, 64, 1)
        safe_show()
        if pixels:
            try:
                pixels.fill((255, 255, 0))  # Yellow
            except:
                pass
        tone(1500, 0.1)
        time.sleep(0.2)
        
        display.fill(1)
        draw_centered_text("BOMB MASTER", 25, 0)
        display.rect(0, 0, 128, 64, 0)
        safe_show()
        if pixels:
            try:
                pixels.fill((255, 100, 0))  # Orange
            except:
                pass
        time.sleep(0.15)
    
    # Final state
    display.fill(0)
    draw_centered_text("BOMB MASTER", 25, 1)
    display.rect(0, 0, 128, 64, 1)
    safe_show()
    
    if pixels:
        try:
            pixels.fill(0)
        except:
            pass
    
    time.sleep(0.2)

# ==================== UI DRAWING FUNCTIONS ====================
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

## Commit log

2025-12-09 Update Bomb Master project with organized structure
    [circuit_diagrams.kicad_sch]
2025-12-09 Clarify independent power switch functionality in hardware pin map
2025-12-09 Update README to clarify independent hardware power switch vs game input button
2025-12-09 Implement high score board with player name input (3 chars, A-Z, before difficulty selection)
2025-12-09 Update CODE_STRUCTURE.md to document high score board and name input features
2025-12-09 Reorganize documentation: separate circuit and system diagrams, update with latest files from assignment4-circuit
    [circuit_diagrams.kicad_sch]
2025-12-09 Final organization: move system diagram to system folder, clean up duplicate files
    [circuit_diagrams.kicad_sch]
